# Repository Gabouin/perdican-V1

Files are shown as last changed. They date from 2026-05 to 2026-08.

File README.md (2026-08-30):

<h1 align="center">
  <br>
  logo perdican
  <br>
  PERDICAN V1
  <br>
</h1>

<h4 align="center">
A STM32 based devboard with an integrated IMU and 14 GPIO pins.
</h4>

<div align="center">






</div>

<p align="center">
  <a href="#about-the-project">About</a> •
  <a href="#repository-structure">Structure</a> •
  <a href="#schematic-on-kicad">Schematic</a> •
  <a href="#pcb-on-kicad">PCB</a> •
  <a href="#bill-of-materials">BOM</a> •
  <a href="#license">License</a> •
  <a href="#contributing">Contributing</a> •
  <a href="#credits">Credits</a>
</p>

<br>
<br>
<p align=center>
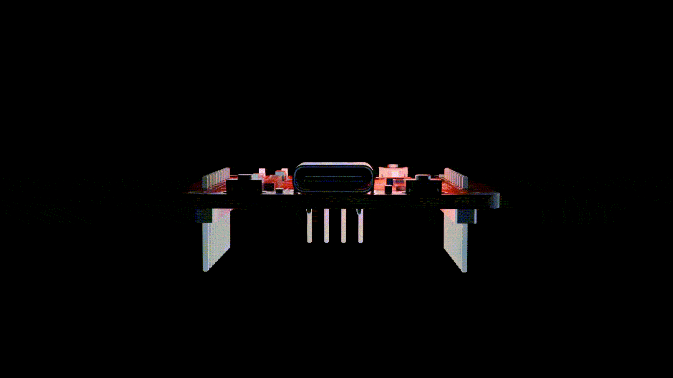
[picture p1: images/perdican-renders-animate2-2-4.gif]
gif render


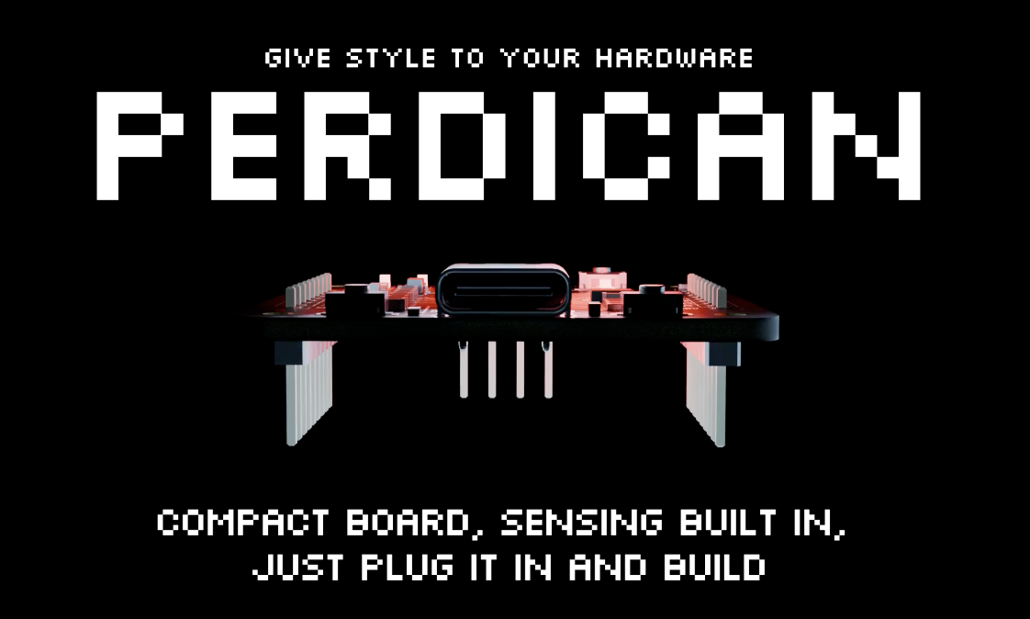
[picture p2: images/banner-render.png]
render banner


</p>

## About the Project

**PERDICAN** is a STM32 based devboard designed with an integrated IMU, GPIO pins, buttons and LEDs

### Features

- **STM32G431CBT6** MCU 32-Bit 170MHz 128KB (128K x 8) FLASH 48-LQFP (7x7)
- **LSM6DS3TR-C** 6 axis IMU with Accelerometer, Gyroscope, Temperature
- **14 GPIO pins** to help make any hardware project
- **4 debugging pins** with SWCLK, SWDIO, GND and 3V3
- **Status LEDs** to see any error from 5V or 3V3
- **GPIO linked LED** to program it without needing an external LED
- **GPIO linked button** to use it without needing an external button
- **BOOT and RESET buttons**
- **USB-C input**
- **pixelated silkscreen art** to improve the overall look
- **Small size** of 3.7*3.9 cm

## Repository Structure

- `src/kicad/` - KiCad project sources
- `src/kicad/cad/` - full 3d model
- `production/` - PCB fabrication files (Gerbers, BOM, Pick & Place)
- `images/` - images used in the README and documentation

## Schematic on KiCad

Source : `src/kicad/schem/`  

Capture d'écran 2026-05-11 171505

## PCB on KiCad

Source : `src/KiCad/pcb/`  

<div align="center">
  <table>
    <tr>
      <td valign="bottom">Capture d'écran 2026-05-11 182925</td>
      <td valign="bottom"></td>
      <td valign="bottom">Capture d'écran 2026-05-11 163710</td>
  </table>
</div>
<div align="center">
  <table>
    <tr>
      <td valign="bottom">Capture d'écran 2026-05-11 165135</td>
      <td valign="bottom">Capture d'écran 2026-05-11 165217
</td>
  </table>
</div>  

> The PCB design is made on only 2 layers, to reduce the cost of the board !
<br>

## Build of the Board

<div align="center">
  <table>
    <tr>
      <td valign="center">perdican irl1</td>
      <td valign="center">perdican irl2</td>
    </tr>
  </table>
</div>
<br>

## Bill of Materials

Source: `production/pcb/bom.csv`

|Designator |Footprint |Quantity|Value |LCSC Part #|
|---|---|---|---|---|
|3V3, 5V, PA3 |0603 |3 |LED |C2286 |
|BOOT |SW-SMD_L3.9-W3.0-P4.45 |1 |BOOT |C455280 |
|C1, C11, C2, C7, C8 |0603 |5 |1uF |C15849 |
|C10, C13, C14, C3, C4, C5, C6, C9|0603 |8 |100nF |C14663 |
|C12 |0603 |1 |10nF |C57112 |
|DEBUG |PinHeader_1x04_P2.54mm_Vertical |1 |Conn_01x04 |C2691448 |
|IMU1 |LGA-14_L3.0-W2.5-P0.50-TL |1 |LSM6DS3TR-C |C967633 |
|J1 |PinHeader_1x09_P2.54mm_Vertical |1 |Header Left |C18213723  |
|J2 |PinHeader_1x09_P2.54mm_Vertical |1 |Header Right |C18213723  |
|PA2 |SW-SMD_L3.9-W3.0-P4.45 |1 |PA2 |C455280 |
|R1, R2 |0603 |2 |5.1k |C23186 |
|R10, R11, R3, R8, R9 |0603 |5 |10k |C25804 |
|R4, R5 |0603 |2 |100k |C25803 |
|R6, R7 |0603 |2 |4.7k |C23162 |
|RESET |SW-SMD_L3.9-W3.0-P4.45 |1 |RESET |C455280 |
|STM32 |LQFP-48_L7.0-W7.0-P0.50-LS9.0-BL|1 |STM32G431CBT6 |C529355 |
|U1 |SOT-23-3 |1 |XC6206PxxxMR |C5446 |
|USB-C1 |USB-C-SMD_TYPE-C-16PIN-2MD-073  |1 |TYPE-C 16PIN 2MD|C2765186 |

## JLPCB order

### LCSC parts 

<div align="center">
  <table>
    <tr>
      <td valign="bottom">LCSC parts</td>
      <td valign="bottom">JLCPCB order</td>
  </table>
</div>  

>The PCB is expensive due to small vias. This will be arranged with bigger vias for the V2. BTW, I am not ordering it, I will do so for the V2.
<br>

## You might also like

- [APX USB HUB](https://github.com/gabouin/APX-USB-HUB) - A PTC-secured USB HUB designed for [Macondo - Hack Club](https://macondo.hackclub.com)
- [HackPad](https://github.com/Gabouin/Hackpad) - A 6-keys macropad designed for [Blueprint - Hack Club](https://blueprint.hackclub.com)
- See more in my [github](https://github.com/gabouin)

## Contributing

Contributions, improvements, and remixes are welcome! Please read the [CONTRIBUTING.md](CONTRIBUTING.md) guide to get started.

## License

This project is licensed under the **MIT License** - see the [LICENSE](LICENSE) file for details.

## Credits

This project uses:

- **KiCad** - PCB design and schematic capture
- **JLCPCB** - PCB manufacturing
- **LCSC** - Parts order
- **Figma** - Silkscreen and banner design
- **Blender** - CAD render
- **[@NotARoomba](https://github.com/notaroomba)** - Readme template

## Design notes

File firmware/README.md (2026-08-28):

# PERDICAN V1 Firmware

Bare-metal firmware for the [PERDICAN V1](https://github.com/Gabouin/perdican-V1)
devboard: **STM32G431CBT6** + **LSM6DS3TR-C** IMU, with a USB CDC console on
the board's USB-C port.

Every pin assignment in this firmware was extracted from the board's own
fabrication netlist (`production/pcb/netlist.ipc`), not transcribed by eye,
so the pin map is exactly what the copper does.

```
  ____  _____ ____  ____ ___ ____    _    _   _
 |  _ \| ____|  _ \|  _ \_ _/ ___|  / \  | \ | |
 | |_) |  _| | |_) | | | | | |     / _ \ |  \| |
 |  __/| |___|  _ <| |_| | | |___ / ___ \| |\  |
 |_|   |_____|_| \_\____/___\____/_/   \_\_| \_|  V1
```

---

## What it does

- Brings SYSCLK to **170 MHz** from the internal HSI16, since the board has
  no crystal, so everything runs off internal oscillators.
- Runs USB from **HSI48 + CRS**, trimmed against the host's start-of-frame.
  This is what lets a crystal-less board do USB at all.
- Talks to the **LSM6DS3TR-C** over I2C1 at 400 kHz: accelerometer,
  gyroscope, temperature, data-ready interrupts and the datasheet self-test.
- Presents a **USB CDC serial console** with an interactive shell. The board
  has no USB-UART bridge, so native USB is the only way to reach a host.
- Reflashes over the same USB-C cable with **no debugger**, via DFU.

Footprint: **~31 KB flash (24%)**, **~7.6 KB RAM (35%)**.

---

## Quick start

```sh
brew install --cask gcc-arm-embedded    # or your distro's arm-none-eabi-gcc
brew install dfu-util                   # for debugger-free flashing

make                                    # builds build/perdican.{elf,bin,hex}
```

Flash it: **hold BOOT, tap RESET, release BOOT**, then:

```sh
make dfu
```

Open the console (the board appears as a USB serial port):

```sh
screen /dev/cu.usbmodem*        # macOS
screen /dev/ttyACM0             # Linux
```

Once firmware is running, later reflashes need no button at all:

```sh
make dfu-reset dfu
```

`dfu-reset` opens the port at 1200 baud and drops DTR; the firmware takes
that as a request to reboot into the ROM bootloader.

---

## The console

```
perdican> help
  help                 this list
  id                   board, clock and chip identity
  uptime               milliseconds since boot

  led on|off|toggle    drive the user LED (PA3)
  btn                  read the user button (PA2)
  vbus                 USB bus power present (PA9)

  imu                  one accel/gyro/temp reading
  imu stream [hz]      stream readings, any key stops
  imu selftest         run the datasheet self-test
  imu regs             dump the key control registers

  i2cscan              probe every address on I2C1

  pins                 expansion header map
  gpio <pin> read      read a header pin (e.g. gpio PB0 read)
  gpio <pin> out 0|1   drive a header pin
  gpio <pin> in [pu|pd]  make a header pin an input

  reset                reboot the board
  dfu                  reboot into the USB DFU bootloader
```

`gpio PA13`/`gpio PA14` refuse to reconfigure without a trailing `force`,
because those pins are SWDIO/SWCLK as well as J2-3/J2-4.

---

## Board pin map

Derived from `netlist.ipc`. Nets with only one pad were treated as
unconnected and are listed as such.

### On-board peripherals

| Function | Pin | Detail |
|---|---|---|
| User LED | **PA3** | R10 (10k) in series, cathode to GND → **active high** |
| User button | **PA2** | R11 (10k) pull-up to 3V3, switch to GND → **active low** |
| IMU SCL | **PB6** | I2C1_SCL, AF4, R7 (4.7k) pull-up |
| IMU SDA | **PB7** | I2C1_SDA, AF4, R6 (4.7k) pull-up |
| IMU INT1 | **PA0** | LSM6DS3TR-C pad 4 |
| IMU INT2 | **PA1** | LSM6DS3TR-C pad 9 |
| USB D− | **PA11** | USB-C A7/B7 |
| USB D+ | **PA12** | USB-C A6/B6 |
| SWDIO | **PA13** | DEBUG-2, also J2-3 |
| SWCLK | **PA14** | DEBUG-3, also J2-4 |
| VBUS sense | **PA9** | R4/R5 100k divider, 5 V → 2.5 V |
| BOOT0 | **PB8** | R3 (10k) to GND, BOOT button to 3V3 |
| NRST | pin 7 | RESET button + C9 (100 nF) |

The IMU is strapped for **I2C** (CS tied to 3V3) with **SA0 grounded**, so
its 7-bit address is **0x6A**.

### Expansion headers (14 GPIO)

```
      J1 (left)                     J2 (right)
   1  GND                        1  GND
   2  +3V3                       2  +3V3
   3  PB10                       3  PA13  (also SWDIO)
   4  PB2                        4  PA14  (also SWCLK)
   5  PB1                        5  PA15
   6  PB0                        6  PB3
   7  PA7                        7  PB4
   8  PA6                        8  PB5
   9  PA5                        9  PB9
```

DEBUG header: `1 = +3V3`, `2 = SWDIO`, `3 = SWCLK`, `4 = GND`.

### Pins that go nowhere

`PA4, PA8, PA10, PB11, PB12, PB13, PB14, PB15, PC13, PC14, PC15, PF0, PF1`
have no copper connection on this board. The firmware parks them in analog
mode, which is ST's recommended lowest-leakage state for unused I/O.

---

## Two hardware notes

**VBAT is not tied to VDD.** Pad 1 has only C10 (100 nF) to +3V3, so it is
AC-coupled and DC-floating. ST requires VBAT be strapped to VDD when no
backup cell is fitted, so the backup domain on this board is out of spec.
**Do not use the RTC, LSE or TAMP backup registers.** This firmware keeps its
reset-persistent state (the DFU magic word) in a `.noinit` SRAM word instead.
Worth fixing in V2: a short from VBAT to 3V3.

**VBUS sense is digital only.** The 100k/100k divider puts 2.5 V on PA9,
above the 2.31 V input-high threshold, so it reads as a clean "USB power
present" flag. PA9 is not an ADC input on STM32G4, so it cannot measure the
actual bus voltage. Margin is modest; a 100k/56k divider would be more
comfortable in V2.

---

## Layout

```
include/          board.h (the pin map), plus driver headers
src/
  startup.c       vector table, reset entry, fault handler
  clock.c         170 MHz PLL, HSI48 + CRS for USB
  board.c         LED, debounced button, VBUS, unused-pin parking
  systick.c       1 kHz tick, millis/micros/delay
  i2c.c           blocking I2C1 master
  lsm6ds3.c       IMU driver incl. self-test
  dfu.c           reboot into the ROM bootloader
  console.c       the command shell
  retarget.c      printf -> USB CDC, plus newlib syscalls
  main.c          bring-up and main loop
  usb/
    usb_device.c  USB device core and control transfers
    usb_desc.c    descriptors
    usb_cdc.c     CDC ACM class, ring buffers
linker/           STM32G431CBT6 memory layout
cmsis/            vendored CMSIS-Core + ST device header
tools/            dfu-touch.sh, openocd.cfg
```

There is no HAL. Drivers are written directly against the register file, so
each one is short enough to read end to end.

---

## Flashing over SWD

The DEBUG header is SWD-only (no NRST pin), so a hard reset means pressing
the RESET button.

```sh
make flash                                  # OpenOCD + ST-Link
openocd -f tools/openocd.cfg                # then: make gdb
```

---

## Details worth knowing if you extend this

- **I2C timing is derived, not generated.** I2C1 is clocked from HSI16 so
  `TIMINGR` stays valid regardless of SYSCLK; the arithmetic behind the two
  constants is written out in `src/i2c.c`.
- **USB PMA is linear on STM32G4** (`PMA_ACCESS = 1`), unlike STM32F1 where
  each 16-bit entry sits at a 32-bit stride. `src/usb/usb_device.c` depends
  on this.
- **The accelerometer full-scale encoding is not in ascending order**
  (`00 = ±2 g`, `01 = ±16 g`, `10 = ±4 g`, `11 = ±8 g`). Getting it wrong
  scales every reading by 8× and looks like a calibration problem.
- **170 MHz needs Range 1 boost mode**, and its entry sequence requires
  stepping through HCLK/2 for at least 1 µs. `src/clock.c` does this.

---

## License

MIT, matching the hardware project. Vendored CMSIS headers keep their
original Apache-2.0 (ARM) and BSD-3-Clause (ST) licenses.

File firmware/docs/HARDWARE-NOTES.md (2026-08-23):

# PERDICAN V1 — hardware notes from writing the firmware

Everything here was derived from the board's own fabrication netlist,
`production/pcb/netlist.ipc`, by counting how many pads sit on each net. A
net with exactly one pad has no copper connection to anything else, however
it may be labelled in the schematic.

---

## Two things worth changing in V2

### 1. VBAT is left floating

`STM32 pad 1 (VBAT)` sits on a net with **one other pad only**: `C10-2`.
`C10-1` goes to `+3V3`. So VBAT is AC-coupled to the 3.3 V rail through a
100 nF capacitor and has **no DC path anywhere**.

ST requires VBAT to be tied to VDD whenever no backup cell is fitted. With
it floating:

- the backup domain has no defined supply,
- the RTC, LSE and TAMP backup registers are unreliable,
- quiescent current can be higher than the datasheet figure.

The core itself runs fine, which is why this is easy to miss.

**Firmware consequence:** this firmware never touches the backup domain. The
DFU reboot flag, which has to survive a warm reset, lives in a `.noinit`
SRAM word instead of a TAMP backup register.

**Fix for V2:** a direct short (or 0 Ω) from VBAT to +3V3. C10 can stay as
the VBAT decoupling cap it was presumably meant to be.

### 2. VBUS sense has little margin

`VBUS —[R4 100k]— PA9 —[R5 100k]— GND`

At 5.0 V VBUS this puts **2.50 V** on PA9. The STM32G4 input-high threshold
is 0.7 × VDD = **2.31 V**, so it reads high — but only by 190 mV, before
accounting for VBUS sagging under load or resistor tolerance.

PA9 is **not an ADC-capable pin** on STM32G4, so the divider cannot be used
to measure bus voltage; it can only ever be a digital present/absent flag.

**Fix for V2:** either a lower ratio (100k/56k gives ~1.8 V, comfortably
below V_IL for "absent" logic if inverted, or move to a divider that lands
near 3.0 V), or route VBUS sense to an ADC-capable pin such as PA4 or PB0 so
the voltage can actually be read.

---

## Confirmed strapping

| Item | Finding | Consequence |
|---|---|---|
| IMU CS (pad 12) | tied to `+3V3` | LSM6DS3TR-C is in **I2C** mode, not SPI |
| IMU SDO/SA0 (pad 1) | tied to `GND` | 7-bit address is **0x6A** |
| IMU SDx/SCx (pads 2, 3) | tied to `GND` | auxiliary/sensor-hub bus unused |
| USB CC1/CC2 | 5.1k to GND (R1, R2) | UFP/device, 500 mA default, no PD |
| LED PA3 | R10 in series, cathode to GND | **active high** |
| Button PA2 | R11 10k to 3V3, switch to GND | **active low**, external pull-up |
| BOOT0 PB8 | R3 10k to GND, button to 3V3 | idles low, usable as GPIO at run time |
| PF0/PF1, PC14/PC15 | unconnected | **no crystal** — internal oscillators only |
| D+ pull-up | none fitted | correct: the G431 has an internal one (`USB_BCDR.DPPU`) |

The missing crystal is why the firmware runs USB from **HSI48 + CRS**,
trimmed against the host's start-of-frame packets. Without CRS, HSI48's ~3%
error is far outside USB's 0.25% requirement and the device would not
enumerate reliably.

---

## Pins with no connection

Exactly one pad on their net, i.e. routed nowhere:

```
PA4   PA8   PA10
PB11  PB12  PB13  PB14  PB15
PC13  PC14  PC15
PF0   PF1
```

These are labelled in the schematic but do not reach a header or a
component. The firmware parks them in analog mode, ST's recommended
lowest-leakage state for unused I/O.

Note that this leaves several genuinely useful peripherals stranded —
notably `PB11`–`PB14` (which include ADC and SPI2 pins). If V2 has header
room, breaking out even two of them would widen what the board can do.

---

## Full expansion map

```
      J1 (left)                     J2 (right)
   1  GND                        1  GND
   2  +3V3                       2  +3V3
   3  PB10                       3  PA13  (also SWDIO, DEBUG-2)
   4  PB2                        4  PA14  (also SWCLK, DEBUG-3)
   5  PB1                        5  PA15
   6  PB0                        6  PB3
   7  PA7                        7  PB4
   8  PA6                        8  PB5
   9  PA5                        9  PB9
```

`DEBUG`: `1 = +3V3`, `2 = SWDIO (PA13)`, `3 = SWCLK (PA14)`, `4 = GND`.

Because PA13/PA14 appear on both the DEBUG header and J2, using J2-3/J2-4 as
ordinary GPIO drops any attached debugger. The console's `gpio` command
requires an explicit `force` argument before it will reconfigure them.

There is no NRST pin on the DEBUG header, so an SWD probe cannot pull the
board out of a bad state by asserting reset — that means the RESET button.
Adding NRST to a 5-pin DEBUG header in V2 would make debugging noticeably
less fiddly.

---

## Peripheral capabilities the pin map allows

Useful to know before picking a project for this board:

| Bus | Pins available | Notes |
|-----|---|---|
| I2C1 | PB6/PB7 | shared with the IMU; pull-ups already fitted |
| I2C3 | PA8/PB5 | PA8 is not broken out, so SCL is unavailable |
| SPI1 | PA5 SCK, PA6 MISO, PA7 MOSI | **all three on J1-9/8/7** — fully usable |
| SPI3 | PB3 SCK, PB4 MISO, PB5 MOSI | **all three on J2-6/7/8** — fully usable |
| USART1 | PB6 TX, PB7 RX | conflicts with the IMU bus |
| USART2 | PA2 TX, PA3 RX | conflicts with the button and LED |
| USART3 | PB10 TX, PB11 RX | TX on J1-3, **RX not broken out** |
| LPUART1 | PA2/PA3 | same conflict as USART2 |
| TIM2 CH1-4 | PA5, PA1, PA2, PA3 | CH1 free on J1-9 |
| TIM3 CH1-4 | PA6, PA7, PB0, PB1 | **all four on J1-8/7/6/5** — good for motors/servos |
| ADC | PB0, PB1, PB2 | three ADC-capable pins, on J1-6/5/4 (check the datasheet for exact channel numbers) |

**TIM3's four channels and SPI1 both landing entirely on J1** is the nicest
accident of this layout — one header gives you either four PWM outputs or a
complete SPI bus.

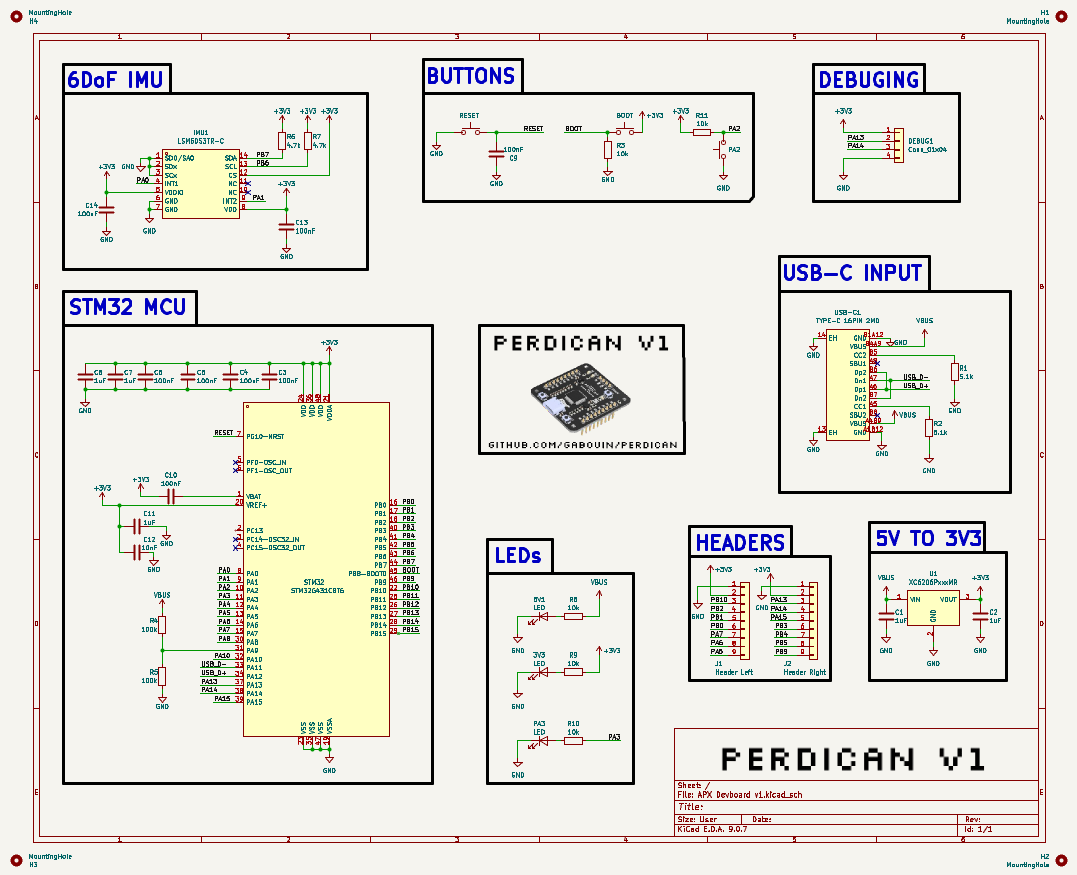
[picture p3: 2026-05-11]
images/SchemPERDICAN.png

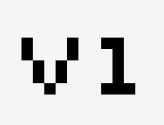
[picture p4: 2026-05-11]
images/typoV1.png

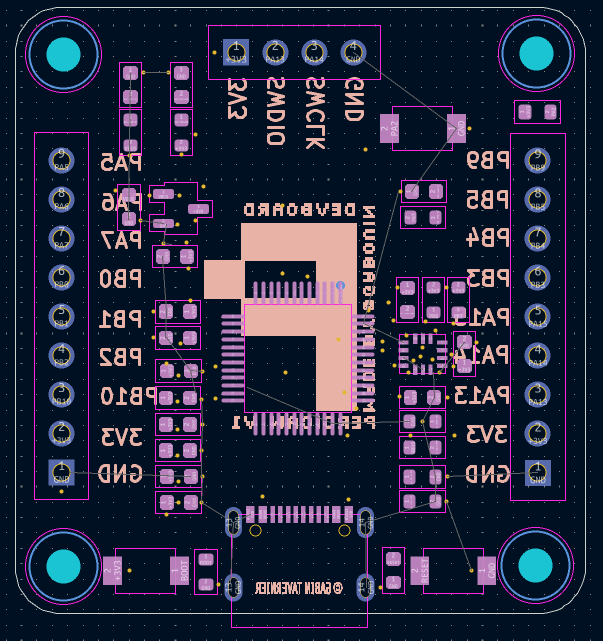
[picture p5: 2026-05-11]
images/BsilkPERDICAN.png

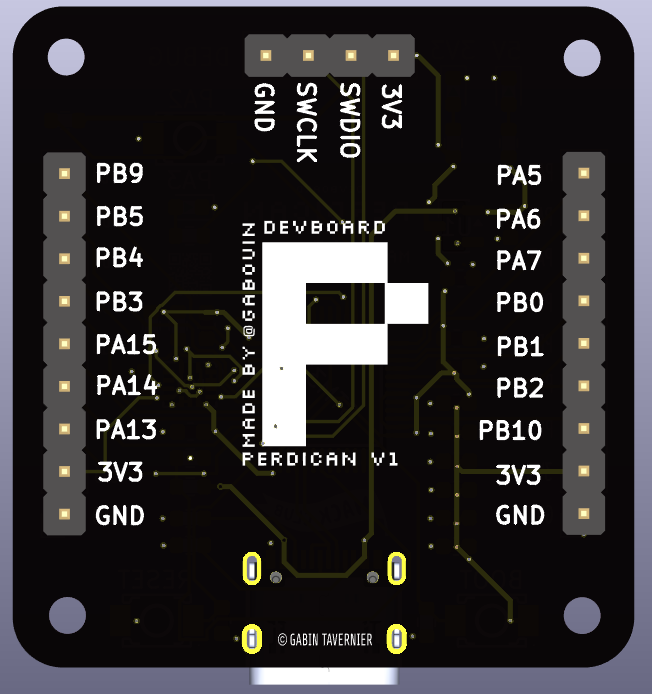
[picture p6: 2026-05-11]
images/PCBbackPERDICAN.png

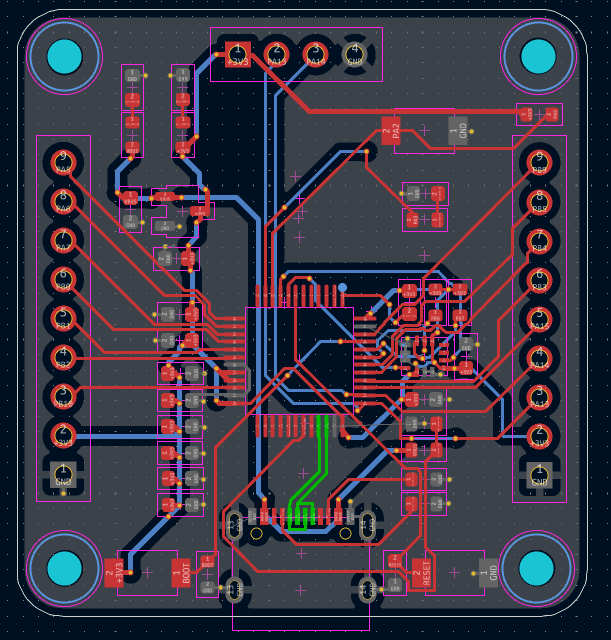
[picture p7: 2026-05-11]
images/PCBwiresPERDICAN.png

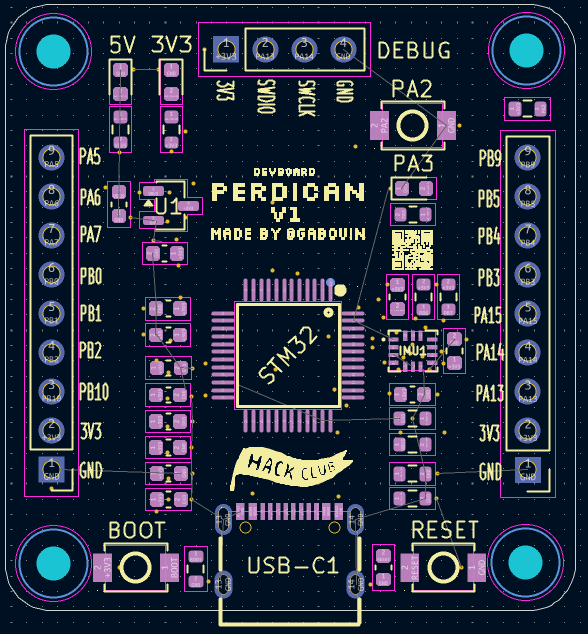
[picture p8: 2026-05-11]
images/FsilkPERDICAN.png

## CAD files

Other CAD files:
src/kicad/cad/Perdican V1.step
src/kicad/cad/perdican.blend

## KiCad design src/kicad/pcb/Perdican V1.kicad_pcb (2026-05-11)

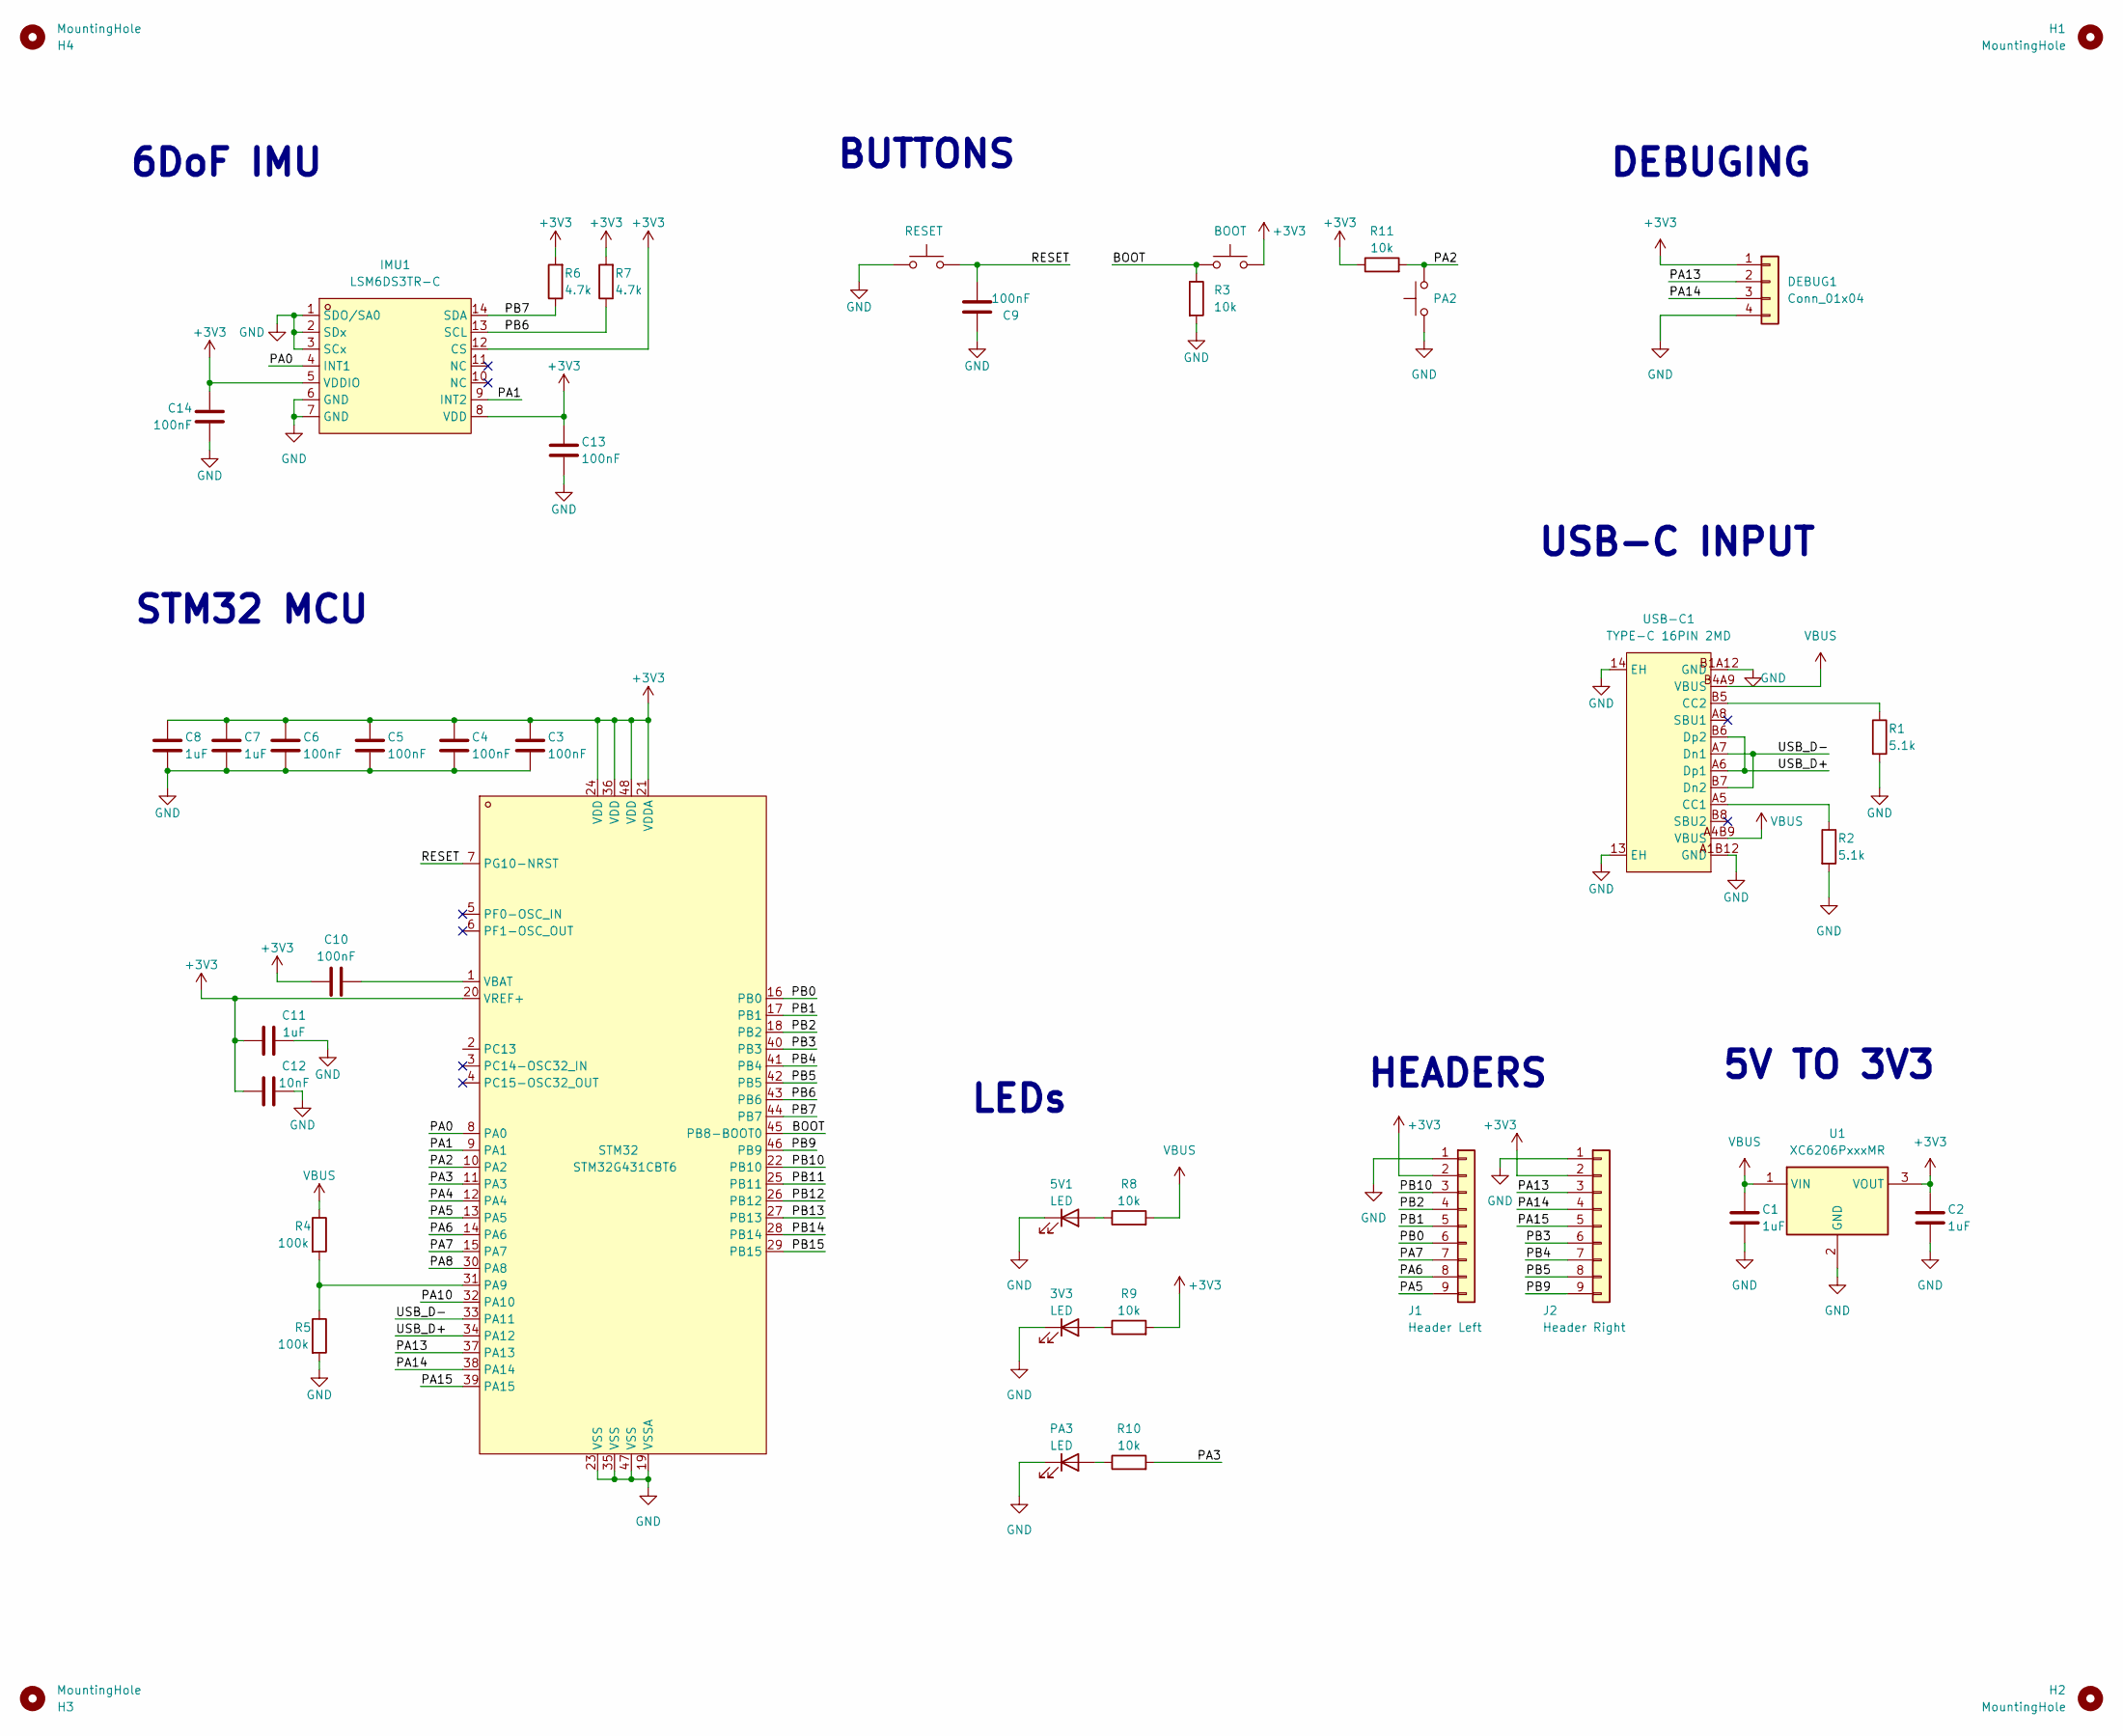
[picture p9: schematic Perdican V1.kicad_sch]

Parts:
3V3, 5V1: LED; LED_0603_1608Metric
BOOT1: BOOT; SW-SMD_L3.9-W3.0-P4.45
C1, C2, C7, C8, C11: 1uF; C_0603_1608Metric
C3, C4, C5, C6, C9, C10, C13, C14: 100nF; C_0603_1608Metric
C12: 10nF; C_0603_1608Metric
DEBUG1: Conn_01x04; PinHeader_1x04_P2.54mm_Vertical
H1, H2, H3, H4: MountingHole; MountingHole_2.2mm_M2
IMU1: LSM6DS3TR-C; LGA-14_L3.0-W2.5-P0.50-TL; MPN LSM6DS3TR-C; LCSC Part C967633
J1: Header Left; PinHeader_1x09_P2.54mm_Vertical
J2: Header Right; PinHeader_1x09_P2.54mm_Vertical
PA2: PA2; SW-SMD_L3.9-W3.0-P4.45
PA3: LED; LED_0603_1608Metric
R1, R2: 5.1k; R_0603_1608Metric
R3, R8, R9, R10, R11: 10k; R_0603_1608Metric
R4, R5: 100k; R_0603_1608Metric
R6, R7: 4.7k; R_0603_1608Metric
RESET1: RESET; SW-SMD_L3.9-W3.0-P4.45
STM32: STM32G431CBT6; LQFP-48_L7.0-W7.0-P0.50-LS9.0-BL; MPN STM32G431CBT6; LCSC Part C529355
U1: XC6206PxxxMR; SOT-23-3
USB-C1: TYPE-C 16PIN 2MD; USB-C-SMD_TYPE-C-16PIN-2MD-073; MPN TYPE-C 16PIN 2MD(073); LCSC Part C2765186

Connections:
+3V3: BOOT1.2, C2.1, C3.1, C4.1, C5.1, C6.1, C7.1, C8.1, C10.1, C11.1, C12.1, C13.1, C14.1, DEBUG1.1, IMU1.5 (VDDIO), IMU1.8 (VDD), IMU1.12 (CS), J1.2, J2.2, R6.2, R7.2, R9.2, R11.1, STM32.20 (VREF+), STM32.21 (VDDA), STM32.24 (VDD), STM32.36 (VDD), STM32.48 (VDD), U1.3 (VOUT); also elsewhere on the board
/BOOT: BOOT1.1, R3.1, STM32.45 (PB8-BOOT0); also elsewhere on the board
/PA0: IMU1.4 (INT1), STM32.8 (PA0)
/PA1: IMU1.9 (INT2), STM32.9 (PA1)
/PA2: PA2.2, R11.2, STM32.10 (PA2)
/PA3: R10.2, STM32.11 (PA3)
/PA4: STM32.12 (PA4)
/PA5: J1.9, STM32.13 (PA5)
/PA6: J1.8, STM32.14 (PA6)
/PA7: J1.7, STM32.15 (PA7)
/PA8: STM32.30 (PA8)
/PA10: STM32.32 (PA10)
/PA13: DEBUG1.2, J2.3, STM32.37 (PA13); also elsewhere on the board
/PA14: DEBUG1.3, J2.4, STM32.38 (PA14); also elsewhere on the board
/PA15: J2.5, STM32.39 (PA15)
/PB0: J1.6, STM32.16 (PB0)
/PB1: J1.5, STM32.17 (PB1)
/PB2: J1.4, STM32.18 (PB2)
/PB3: J2.6, STM32.40 (PB3)
/PB4: J2.7, STM32.41 (PB4)
/PB5: J2.8, STM32.42 (PB5)
/PB6: IMU1.13 (SCL), R7.1, STM32.43 (PB6)
/PB7: IMU1.14 (SDA), R6.1, STM32.44 (PB7)
/PB9: J2.9, STM32.46 (PB9)
/PB10: J1.3, STM32.22 (PB10)
/PB11: STM32.25 (PB11)
/PB12: STM32.26 (PB12)
/PB13: STM32.27 (PB13)
/PB14: STM32.28 (PB14)
/RESET: C9.2, RESET1.2, STM32.7 (PG10-NRST); also elsewhere on the board
/USB_D+: STM32.34 (PA12), USB-C1.A6 (Dp1), USB-C1.B6 (Dp2)
/USB_D-: STM32.33 (PA11), USB-C1.A7 (Dn1), USB-C1.B7 (Dn2)
GND: 3V3.1 (K), 5V1.1 (K), C1.2, C2.2, C3.2, C4.2, C5.2, C6.2, C7.2, C8.2, C9.1, C11.2, C12.2, C13.2, C14.2, DEBUG1.4, IMU1.1 (SDO/SA0), IMU1.2 (SDx), IMU1.3 (SCx), IMU1.6 (GND), IMU1.7 (GND), J1.1, J2.1, PA2.1, PA3.1 (K), R1.2, R2.2, R3.2, R5.2, RESET1.1, STM32.19 (VSSA), STM32.23 (VSS), STM32.35 (VSS), STM32.47 (VSS), U1.2 (GND), USB-C1.13 (EH), USB-C1.14 (EH), USB-C1.A1B12 (GND), USB-C1.B1A12 (GND); also elsewhere on the board
unnamed: 3V3.2 (A), R9.1
unnamed 34: 5V1.2 (A), R8.1; also elsewhere on the board
unnamed: PA3.2 (A), R10.1
unnamed: R4.2, R5.1, STM32.31 (PA9)
unnamed: C10.2, STM32.1 (VBAT)
unnamed: R2.1, USB-C1.A5 (CC1)
unnamed: R1.1, USB-C1.B5 (CC2)
VBUS: C1.1, R4.1, R8.2, U1.1 (VIN), USB-C1.A4B9 (VBUS), USB-C1.B4A9 (VBUS)

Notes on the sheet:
LEDs
BUTTONS
6DoF IMU
USB-C INPUT
STM32 MCU
HEADERS
DEBUGING
5V TO 3V3

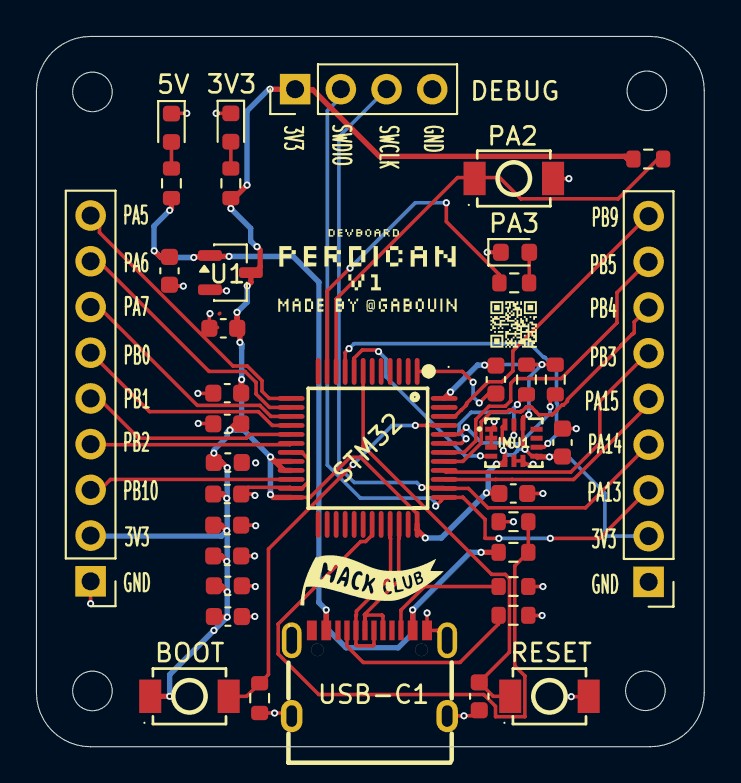
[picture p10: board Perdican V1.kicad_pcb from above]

Board: 2 copper layers, 37.1 x 39.5 mm, 42 parts (0 on the bottom side), 34 nets.

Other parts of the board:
5V: LED; LED_0603_1608Metric
BOOT: BOOT; SW-SMD_L3.9-W3.0-P4.45
DEBUG: Conn_01x04; PinHeader_1x04_P2.54mm_Vertical
RESET: RESET; SW-SMD_L3.9-W3.0-P4.45

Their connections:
+3V3: BOOT.2, DEBUG.1; also elsewhere on the board
/BOOT: BOOT.1; also elsewhere on the board
/PA13: DEBUG.2; also elsewhere on the board
/PA14: DEBUG.3; also elsewhere on the board
/RESET: RESET.2; also elsewhere on the board
GND: 5V.1 (K), DEBUG.4, RESET.1; also elsewhere on the board
unnamed 34: 5V.2 (A); also elsewhere on the board

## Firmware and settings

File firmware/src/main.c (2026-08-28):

#include "board.h"
#include "clock.h"
#include "systick.h"
#include "gpio.h"
#include "i2c.h"
#include "lsm6ds3.h"
#include "console.h"
#include "usb_device.h"
#include "usb_cdc.h"
#include "dfu.h"
#include <stdio.h>

typedef enum {
    STATUS_OK = 0,
    STATUS_IMU_NO_ANSWER,
    STATUS_IMU_WRONG_ID,
} status_t;

static status_t s_status;
extern void retarget_init(void);

static status_t bring_up_imu(void)
{
    i2c_bus_recover();
    i2c_init(I2C_SPEED_400K);

    uint8_t id = 0;
    if (i2c_read_reg(IMU_I2C_ADDR7, LSM6_WHO_AM_I, &id) != I2C_OK)
        return STATUS_IMU_NO_ANSWER;

    if (id != LSM6_WHO_AM_I_VALUE)
        return STATUS_IMU_WRONG_ID;

    if (lsm6ds3_init(0) != I2C_OK)
        return STATUS_IMU_NO_ANSWER;

    lsm6ds3_enable_drdy(true, true);

    return STATUS_OK;
}

static void led_error_pattern(uint8_t count)
{
    static uint32_t next;
    static uint8_t  phase;

    const uint8_t  pulses = (uint8_t)(count * 2u);
    const uint32_t step   = (phase >= pulses) ? 900u
                          : ((phase & 1u) ? 160u : 140u);

    if ((millis() - next) < step)
        return;

    next = millis();

    if (phase >= pulses) {
        phase = 0;
    } else {
        led_set((phase & 1u) == 0u);
        phase++;
        return;
    }

    led_set(false);
}

int main(void)
{
    board_init();

    if (dfu_boot_button_held())
        dfu_reboot_to_bootloader();

    led_set(true);
    delay_ms(80);
    led_set(false);

    s_status = bring_up_imu();

    clock_init_usb();
    cdc_init();
    usb_init();
    retarget_init();
    console_init();

    bool     banner_sent = false;
    uint32_t heartbeat   = millis();

    for (;;) {
        const bool connected = cdc_is_connected();

        if (connected && !banner_sent) {
            banner_sent = true;
            console_banner();

            switch (s_status) {
            case STATUS_IMU_NO_ANSWER:
                printf("WARNING: no answer from the IMU at 0x%02X on I2C1.\r\n",
                       IMU_I2C_ADDR7);
                printf("         Check R6/R7 (4.7k pull-ups) and the LGA-14 solder joints.\r\n\r\n");
                break;
            case STATUS_IMU_WRONG_ID:
                printf("WARNING: a device answered at 0x%02X but WHO_AM_I was not 0x%02X.\r\n\r\n",
                       IMU_I2C_ADDR7, LSM6_WHO_AM_I_VALUE);
                break;
            default:
                break;
            }

            led_set(true);
            console_init();
        }

        if (!connected)
            banner_sent = false;

        console_poll();

        if (button_take_press()) {
            led_toggle();
            if (connected) {
                printf("\r\n[button] LED %s\r\n", led_get() ? "on" : "off");
                cdc_puts("perdican> ");
                cdc_flush();
            }
        }

        if (s_status != STATUS_OK) {
            led_error_pattern(s_status == STATUS_IMU_NO_ANSWER ? 2u : 3u);
        } else if (connected) {
        } else if (millis() - heartbeat >= 1000u) {
            heartbeat = millis();
            led_toggle();
        }

        __asm volatile ("wfi");
    }
}

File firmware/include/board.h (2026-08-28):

#ifndef PERDICAN_BOARD_H
#define PERDICAN_BOARD_H

#include "stm32g431xx.h"
#include <stdint.h>
#include <stdbool.h>

#define BOARD_SYSCLK_HZ     170000000UL
#define BOARD_HCLK_HZ       170000000UL
#define BOARD_PCLK1_HZ      170000000UL
#define BOARD_PCLK2_HZ      170000000UL
#define BOARD_HSI16_HZ      16000000UL

#define LED_PORT            GPIOA
#define LED_PIN             3u
#define LED_ACTIVE_HIGH     1

#define BTN_PORT            GPIOA
#define BTN_PIN             2u
#define BTN_ACTIVE_LOW      1

#define IMU_I2C             I2C1
#define IMU_I2C_ADDR7       0x6Au

#define IMU_SCL_PORT        GPIOB
#define IMU_SCL_PIN         6u
#define IMU_SCL_AF          4u
#define IMU_SDA_PORT        GPIOB
#define IMU_SDA_PIN         7u
#define IMU_SDA_AF          4u

#define IMU_INT1_PORT       GPIOA
#define IMU_INT1_PIN        0u
#define IMU_INT2_PORT       GPIOA
#define IMU_INT2_PIN        1u

#define USB_DM_PORT         GPIOA
#define USB_DM_PIN          11u
#define USB_DP_PORT         GPIOA
#define USB_DP_PIN          12u

#define VBUS_PORT           GPIOA
#define VBUS_PIN            9u

#define SWDIO_PORT          GPIOA
#define SWDIO_PIN           13u
#define SWCLK_PORT          GPIOA
#define SWCLK_PIN           14u

#define BOOT0_PORT          GPIOB
#define BOOT0_PIN           8u

typedef struct {
    const char *name;
    GPIO_TypeDef *port;
    uint8_t       pin;
    uint8_t       header;
    uint8_t       position;
} board_gpio_t;

#define BOARD_GPIO_COUNT    14
extern const board_gpio_t board_gpios[BOARD_GPIO_COUNT];

const board_gpio_t *board_gpio_find(const char *name);

bool board_pin_is_swd(GPIO_TypeDef *port, uint8_t pin);

void board_init(void);

void led_set(bool on);
void led_toggle(void);
bool led_get(void);

bool button_raw(void);
bool button_pressed(void);
bool button_take_press(void);

bool vbus_present(void);

#endif

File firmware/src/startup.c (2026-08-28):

#include "stm32g431xx.h"
#include <stdint.h>
#include <string.h>

extern uint32_t _sidata, _sdata, _edata, _sbss, _ebss, _estack;

extern int  main(void);
void Reset_Handler(void);
void Default_Handler(void);

extern void dfu_check_reboot_magic(void);

#define ALIAS(f) __attribute__((weak, alias(#f)))

void NMI_Handler(void)              ALIAS(Default_Handler);
void HardFault_Handler(void)        ALIAS(Default_Handler);
void MemManage_Handler(void)        ALIAS(Default_Handler);
void BusFault_Handler(void)         ALIAS(Default_Handler);
void UsageFault_Handler(void)       ALIAS(Default_Handler);
void SVC_Handler(void)              ALIAS(Default_Handler);
void DebugMon_Handler(void)         ALIAS(Default_Handler);
void PendSV_Handler(void)           ALIAS(Default_Handler);
void SysTick_Handler(void)          ALIAS(Default_Handler);

void WWDG_IRQHandler(void)                      ALIAS(Default_Handler);
void PVD_PVM_IRQHandler(void)                   ALIAS(Default_Handler);
void RTC_TAMP_LSECSS_IRQHandler(void)           ALIAS(Default_Handler);
void RTC_WKUP_IRQHandler(void)                  ALIAS(Default_Handler);
void FLASH_IRQHandler(void)                     ALIAS(Default_Handler);
void RCC_IRQHandler(void)                       ALIAS(Default_Handler);
void EXTI0_IRQHandler(void)                     ALIAS(Default_Handler);
void EXTI1_IRQHandler(void)                     ALIAS(Default_Handler);
void EXTI2_IRQHandler(void)                     ALIAS(Default_Handler);
void EXTI3_IRQHandler(void)                     ALIAS(Default_Handler);
void EXTI4_IRQHandler(void)                     ALIAS(Default_Handler);
void DMA1_Channel1_IRQHandler(void)             ALIAS(Default_Handler);
void DMA1_Channel2_IRQHandler(void)             ALIAS(Default_Handler);
void DMA1_Channel3_IRQHandler(void)             ALIAS(Default_Handler);
void DMA1_Channel4_IRQHandler(void)             ALIAS(Default_Handler);
void DMA1_Channel5_IRQHandler(void)             ALIAS(Default_Handler);
void DMA1_Channel6_IRQHandler(void)             ALIAS(Default_Handler);
void DMA1_Channel7_IRQHandler(void)             ALIAS(Default_Handler);
void ADC1_2_IRQHandler(void)                    ALIAS(Default_Handler);
void USB_HP_IRQHandler(void)                    ALIAS(Default_Handler);
void USB_LP_IRQHandler(void)                    ALIAS(Default_Handler);
void FDCAN1_IT0_IRQHandler(void)                ALIAS(Default_Handler);
void FDCAN1_IT1_IRQHandler(void)                ALIAS(Default_Handler);
void EXTI9_5_IRQHandler(void)                   ALIAS(Default_Handler);
void TIM1_BRK_TIM15_IRQHandler(void)            ALIAS(Default_Handler);
void TIM1_UP_TIM16_IRQHandler(void)             ALIAS(Default_Handler);
void TIM1_TRG_COM_TIM17_IRQHandler(void)        ALIAS(Default_Handler);
void TIM1_CC_IRQHandler(void)                   ALIAS(Default_Handler);
void TIM2_IRQHandler(void)                      ALIAS(Default_Handler);
void TIM3_IRQHandler(void)                      ALIAS(Default_Handler);
void TIM4_IRQHandler(void)                      ALIAS(Default_Handler);
void I2C1_EV_IRQHandler(void)                   ALIAS(Default_Handler);
void I2C1_ER_IRQHandler(void)                   ALIAS(Default_Handler);
void I2C2_EV_IRQHandler(void)                   ALIAS(Default_Handler);
void I2C2_ER_IRQHandler(void)                   ALIAS(Default_Handler);
void SPI1_IRQHandler(void)                      ALIAS(Default_Handler);
void SPI2_IRQHandler(void)                      ALIAS(Default_Handler);
void USART1_IRQHandler(void)                    ALIAS(Default_Handler);
void USART2_IRQHandler(void)                    ALIAS(Default_Handler);
void USART3_IRQHandler(void)                    ALIAS(Default_Handler);
void EXTI15_10_IRQHandler(void)                 ALIAS(Default_Handler);
void RTC_Alarm_IRQHandler(void)                 ALIAS(Default_Handler);
void USBWakeUp_IRQHandler(void)                 ALIAS(Default_Handler);
void TIM8_BRK_IRQHandler(void)                  ALIAS(Default_Handler);
void TIM8_UP_IRQHandler(void)                   ALIAS(Default_Handler);
void TIM8_TRG_COM_IRQHandler(void)              ALIAS(Default_Handler);
void TIM8_CC_IRQHandler(void)                   ALIAS(Default_Handler);
void ADC3_IRQHandler(void)                      ALIAS(Default_Handler);
void FMC_IRQHandler(void)                       ALIAS(Default_Handler);
void LPTIM1_IRQHandler(void)                    ALIAS(Default_Handler);
void TIM5_IRQHandler(void)                      ALIAS(Default_Handler);
void SPI3_IRQHandler(void)                      ALIAS(Default_Handler);
void UART4_IRQHandler(void)                     ALIAS(Default_Handler);
void UART5_IRQHandler(void)                     ALIAS(Default_Handler);
void TIM6_DAC_IRQHandler(void)                  ALIAS(Default_Handler);
void TIM7_IRQHandler(void)                      ALIAS(Default_Handler);
void DMA2_Channel1_IRQHandler(void)             ALIAS(Default_Handler);
void DMA2_Channel2_IRQHandler(void)             ALIAS(Default_Handler);
void DMA2_Channel3_IRQHandler(void)             ALIAS(Default_Handler);
void DMA2_Channel4_IRQHandler(void)             ALIAS(Default_Handler);
void DMA2_Channel5_IRQHandler(void)             ALIAS(Default_Handler);
void ADC4_IRQHandler(void)                      ALIAS(Default_Handler);
void ADC5_IRQHandler(void)                      ALIAS(Default_Handler);
void UCPD1_IRQHandler(void)                     ALIAS(Default_Handler);
void COMP1_2_3_IRQHandler(void)                 ALIAS(Default_Handler);
void COMP4_5_6_IRQHandler(void)                 ALIAS(Default_Handler);
void COMP7_IRQHandler(void)                     ALIAS(Default_Handler);
void HRTIM1_Master_IRQHandler(void)             ALIAS(Default_Handler);
void HRTIM1_TIMA_IRQHandler(void)               ALIAS(Default_Handler);
void HRTIM1_TIMB_IRQHandler(void)               ALIAS(Default_Handler);
void HRTIM1_TIMC_IRQHandler(void)               ALIAS(Default_Handler);
void HRTIM1_TIMD_IRQHandler(void)               ALIAS(Default_Handler);
void HRTIM1_TIME_IRQHandler(void)               ALIAS(Default_Handler);
void HRTIM1_FLT_IRQHandler(void)                ALIAS(Default_Handler);
void HRTIM1_TIMF_IRQHandler(void)               ALIAS(Default_Handler);
void CRS_IRQHandler(void)                       ALIAS(Default_Handler);
void SAI1_IRQHandler(void)                      ALIAS(Default_Handler);
void TIM20_BRK_IRQHandler(void)                 ALIAS(Default_Handler);
void TIM20_UP_IRQHandler(void)                  ALIAS(Default_Handler);
void TIM20_TRG_COM_IRQHandler(void)             ALIAS(Default_Handler);
void TIM20_CC_IRQHandler(void)                  ALIAS(Default_Handler);
void FPU_IRQHandler(void)                       ALIAS(Default_Handler);
void I2C4_EV_IRQHandler(void)                   ALIAS(Default_Handler);
void I2C4_ER_IRQHandler(void)                   ALIAS(Default_Handler);
void SPI4_IRQHandler(void)                      ALIAS(Default_Handler);
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

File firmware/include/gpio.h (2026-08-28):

#ifndef PERDICAN_GPIO_H
#define PERDICAN_GPIO_H

#include "stm32g431xx.h"
#include <stdint.h>
#include <stdbool.h>

typedef enum {
    GPIO_MODE_INPUT  = 0u,
    GPIO_MODE_OUTPUT = 1u,
    GPIO_MODE_AF     = 2u,
    GPIO_MODE_ANALOG = 3u,
} gpio_mode_t;

typedef enum {
    GPIO_PULL_NONE = 0u,
    GPIO_PULL_UP   = 1u,
    GPIO_PULL_DOWN = 2u,
} gpio_pull_t;

typedef enum {
    GPIO_SPEED_LOW      = 0u,
    GPIO_SPEED_MEDIUM   = 1u,
    GPIO_SPEED_HIGH     = 2u,
    GPIO_SPEED_VERYHIGH = 3u,
} gpio_speed_t;

typedef enum {
    GPIO_PP = 0u,
    GPIO_OD = 1u,
} gpio_otype_t;

static inline void gpio_set_mode(GPIO_TypeDef *p, uint8_t pin, gpio_mode_t m)
{
    p->MODER = (p->MODER & ~(3u << (pin * 2u))) | ((uint32_t)m << (pin * 2u));
}

static inline void gpio_set_pull(GPIO_TypeDef *p, uint8_t pin, gpio_pull_t pu)
{
    p->PUPDR = (p->PUPDR & ~(3u << (pin * 2u))) | ((uint32_t)pu << (pin * 2u));
}

static inline void gpio_set_speed(GPIO_TypeDef *p, uint8_t pin, gpio_speed_t s)
{
    p->OSPEEDR = (p->OSPEEDR & ~(3u << (pin * 2u))) | ((uint32_t)s << (pin * 2u));
}

static inline void gpio_set_otype(GPIO_TypeDef *p, uint8_t pin, gpio_otype_t t)
{
    if (t == GPIO_OD)
        p->OTYPER |= (1u << pin);
    else
        p->OTYPER &= ~(1u << pin);
}

static inline void gpio_set_af(GPIO_TypeDef *p, uint8_t pin, uint8_t af)
{
    const uint8_t idx = pin >> 3u;
    const uint8_t sh  = (pin & 7u) * 4u;
    p->AFR[idx] = (p->AFR[idx] & ~(0xFu << sh)) | ((uint32_t)af << sh);
}

static inline void gpio_write(GPIO_TypeDef *p, uint8_t pin, bool high)
{
    p->BSRR = high ? (1u << pin) : (1u << (pin + 16u));
}

static inline void gpio_high(GPIO_TypeDef *p, uint8_t pin)  { p->BSRR = 1u << pin; }
static inline void gpio_low(GPIO_TypeDef *p, uint8_t pin)   { p->BSRR = 1u << (pin + 16u); }

static inline void gpio_toggle(GPIO_TypeDef *p, uint8_t pin)
{
    p->BSRR = (p->ODR & (1u << pin)) ? (1u << (pin + 16u)) : (1u << pin);
}

static inline bool gpio_read(GPIO_TypeDef *p, uint8_t pin)
{
    return (p->IDR & (1u << pin)) != 0u;
}

static inline bool gpio_read_output(GPIO_TypeDef *p, uint8_t pin)
{
    return (p->ODR & (1u << pin)) != 0u;
}

static inline void gpio_config_output(GPIO_TypeDef *p, uint8_t pin,
                                      gpio_otype_t t, gpio_speed_t s)
{
    gpio_set_otype(p, pin, t);
    gpio_set_speed(p, pin, s);
    gpio_set_pull(p, pin, GPIO_PULL_NONE);
    gpio_set_mode(p, pin, GPIO_MODE_OUTPUT);
}

static inline void gpio_config_input(GPIO_TypeDef *p, uint8_t pin, gpio_pull_t pu)
{
    gpio_set_pull(p, pin, pu);
    gpio_set_mode(p, pin, GPIO_MODE_INPUT);
}

static inline void gpio_config_af(GPIO_TypeDef *p, uint8_t pin, uint8_t af,
                                  gpio_otype_t t, gpio_pull_t pu, gpio_speed_t s)
{
    gpio_set_af(p, pin, af);
    gpio_set_otype(p, pin, t);
    gpio_set_pull(p, pin, pu);
    gpio_set_speed(p, pin, s);
    gpio_set_mode(p, pin, GPIO_MODE_AF);
}

static inline void gpio_config_analog(GPIO_TypeDef *p, uint8_t pin)
{
    gpio_set_pull(p, pin, GPIO_PULL_NONE);
    gpio_set_mode(p, pin, GPIO_MODE_ANALOG);
}

#endif

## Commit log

2026-05-11 Add BOM CSV file for PCB components
    [bom.csv]
2026-05-11 change folder of kicad pro
2026-05-11 Rename src/kicad/Perdican V1.kicad_pcb to src/kicad/pcb/Perdican V1.kicad_pcb
    [Perdican V1.kicad_pcb]
2026-05-11 Rename src/kicad/Perdican V1.kicad_sch to src/kicad/schem/Perdican V1.kicad_sch
    [Perdican V1.kicad_sch]
2026-05-11 Rename src/kicad/Perdican V1.step to src/kicad/cad/Perdican V1.step
    [Perdican V1.step]
2026-05-11 Add PERDICAN_bom.csv to production/pcb directory
    [PERDICAN_bom.csv]
2026-08-23 Add STM32G431 firmware with USB CDC console and IMU driver
2026-08-28 modify the board init in the firmware to debug the firmware flashing in the board
2026-08-30 Add build section with images to README
    Added a new section for the board build with images.
